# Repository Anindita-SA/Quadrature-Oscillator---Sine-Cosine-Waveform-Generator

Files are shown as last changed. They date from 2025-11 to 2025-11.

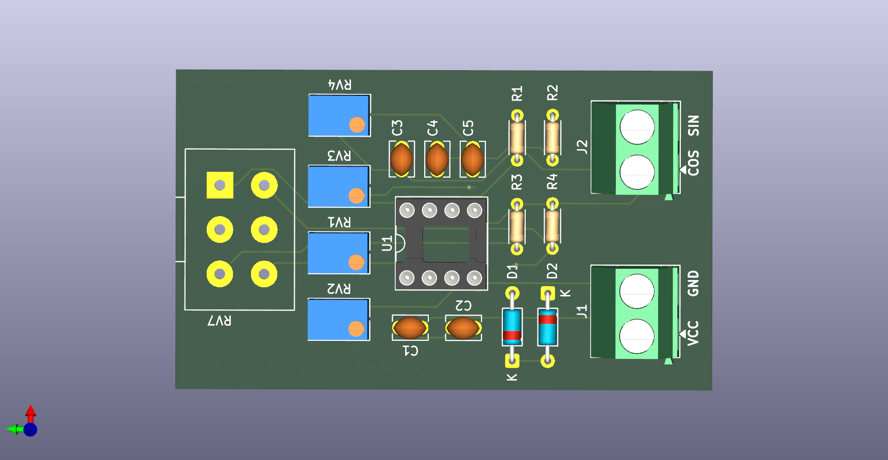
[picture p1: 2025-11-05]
PCB design for Quadrarure oscillator/Final PCB for 1khz Sine wave generator 123.png

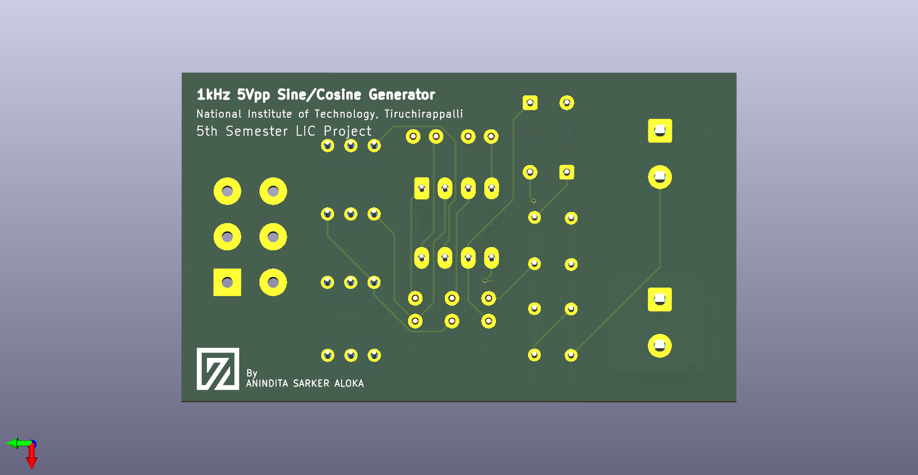
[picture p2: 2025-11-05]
PCB design for Quadrarure oscillator/Final PCB for 1khz Sine wave generator 12.png

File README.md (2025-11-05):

# Quadrature Oscillator - Sine/Cosine Waveform Generator

⚠️ **WORK IN PROGRESS** - Hardware optimization ongoing

## Overview

1kHz quadrature oscillator generating simultaneous sine and cosine waveforms with 90° phase relationship using op-amp integrators.

**Key Specs:**
- Frequency: 1 kHz
- Phase Difference: 90° (quadrature)
- Output: ~2.4V peak
- Supply: ±15V
- IC: LM358 dual op-amp

## Circuit Design



### Topology

State-variable quadrature oscillator implementing:

```
d(sine)/dt = ω × cosine
d(cosine)/dt = -ω × sine
```

### Schematic

[Final PCB for 1khz Sine wave generator 2.pdf](https://github.com/user-attachments/files/23353181/Final.PCB.for.1khz.Sine.wave.generator.2.pdf)

### Components

| Component | Value | Function |
|---|---|---|
| R1, R2, R3, R4 | 1.6kΩ | Frequency setting |
| C1, C2, C3 | 100nF | Integrator capacitors |
| R5, R7 | 1kΩ | Bias network |
| R6, R10 | 8kΩ | Voltage divider |
| D1, D2 | 1N4148 | Amplitude limiting |
| U1, U2 | LM358 | Op-amps (2 ICs) |

## Calculations

**Frequency:**
```
f = 1/(2πRC) = 1/(2π × 1.6kΩ × 100nF) ≈ 995 Hz
Measured: 1.01 kHz (±1%)
```

**Output Amplitude:**
```
V_bias = 15V × 1kΩ/9kΩ = 1.67V
V_peak = V_bias + V_diode = 1.67V + 0.7V = 2.37V
Measured: ~2.4V ✓
```

**Phase:**
```
Target: 90°
Measured: 83-85° (within tolerance)
```

## Performance





| Parameter | Target | Simulation | Hardware |
|---|---|---|---|
| Frequency | 1000 Hz | 1009 Hz | 1030 Hz |
| Phase | 90° | 91.7° | 83-85° |
| Amplitude | ~5V pp | 4.68V pp | ~2.4V |

## Design Evolution

1. **Wien Bridge** → Abandoned (complex amplitude control)
2. **All-Pass Filter** → Abandoned (wrong phase shift)
3. **Quadrature Oscillator** → Current (functional, optimizing)

## Known Issues

- **Hardware distortion** - LM358 slew rate limiting + breadboard parasitics
- **Phase accuracy** - Component tolerances cause 5-7° deviation
- **Amplitude variation** - Working on stabilization

## To-Do

- [ ] PCB implementation
- [ ] Add frequency adjustment potentiometer

## Files

- [[schematic.png](https://github.com/Anindita-SA/Quadrature-Oscillator-Sine-Cosine-Waveform-Generator/blob/61d378de57019a960dd601e74cefbcc4ff721f99/Final%20PCB%20for%201khz%20Sine%20w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)] - Circuit diagram
- [[simulation.asc](https://github.com/Anindita-SA/Quadrature-Oscillator-Sine-Cosine-Waveform-Generator/tree/61d378de57019a960dd601e74cefbcc4ff721f99/LTSpice%20simulation%20for%201kHz%2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)] - LTspice file
- `calculations.md` - Design math
- `troubleshooting.md` - Issues log

## Build Notes

**Critical:**
- Use **film capacitors** for C1, C2, C3 (not ceramic)
- Verify component markings ("103" = 10nF, "104" = 100nF)
- Add 0.1µF decoupling caps close to IC pins
- Keep wires short on breadboard

## References

- Horowitz & Hill, "Art of Electronics" (3rd Ed., §5.17)
- [YouTube reference video](https://www.youtube.com/watch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)

## License

Educational/open source - standard quadrature oscillator topology

## Contact

[[Github](https://github.com/Anindita-SA)]

**Status:** Active development - contributions welcome

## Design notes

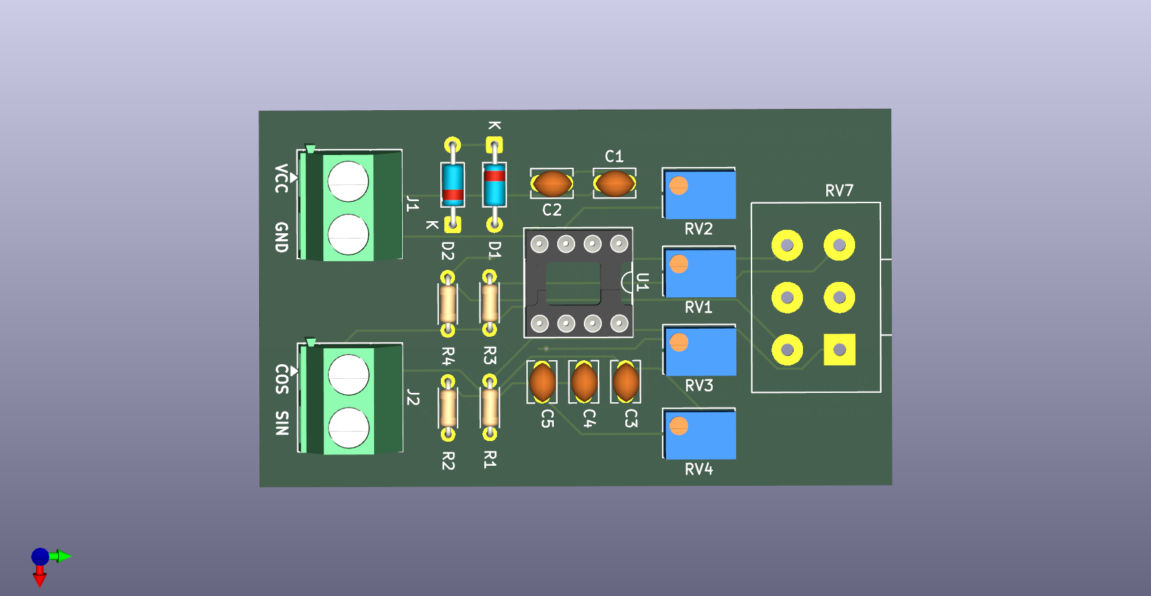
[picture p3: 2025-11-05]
Final PCB for 1khz Sine wave generator 1.png

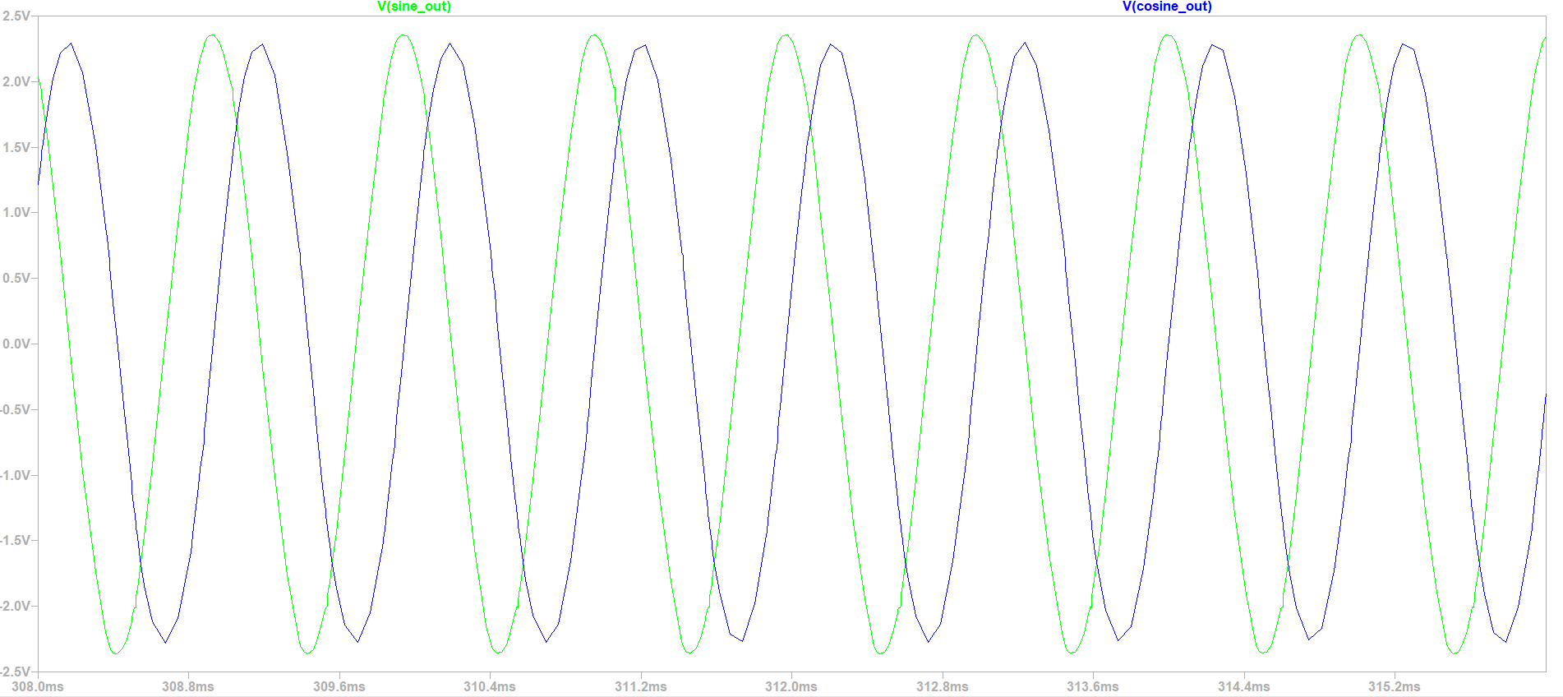
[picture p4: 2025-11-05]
LTSpice simulation for 1kHz SineCosine Generator/Screenshot 2025-11-05 121047.png

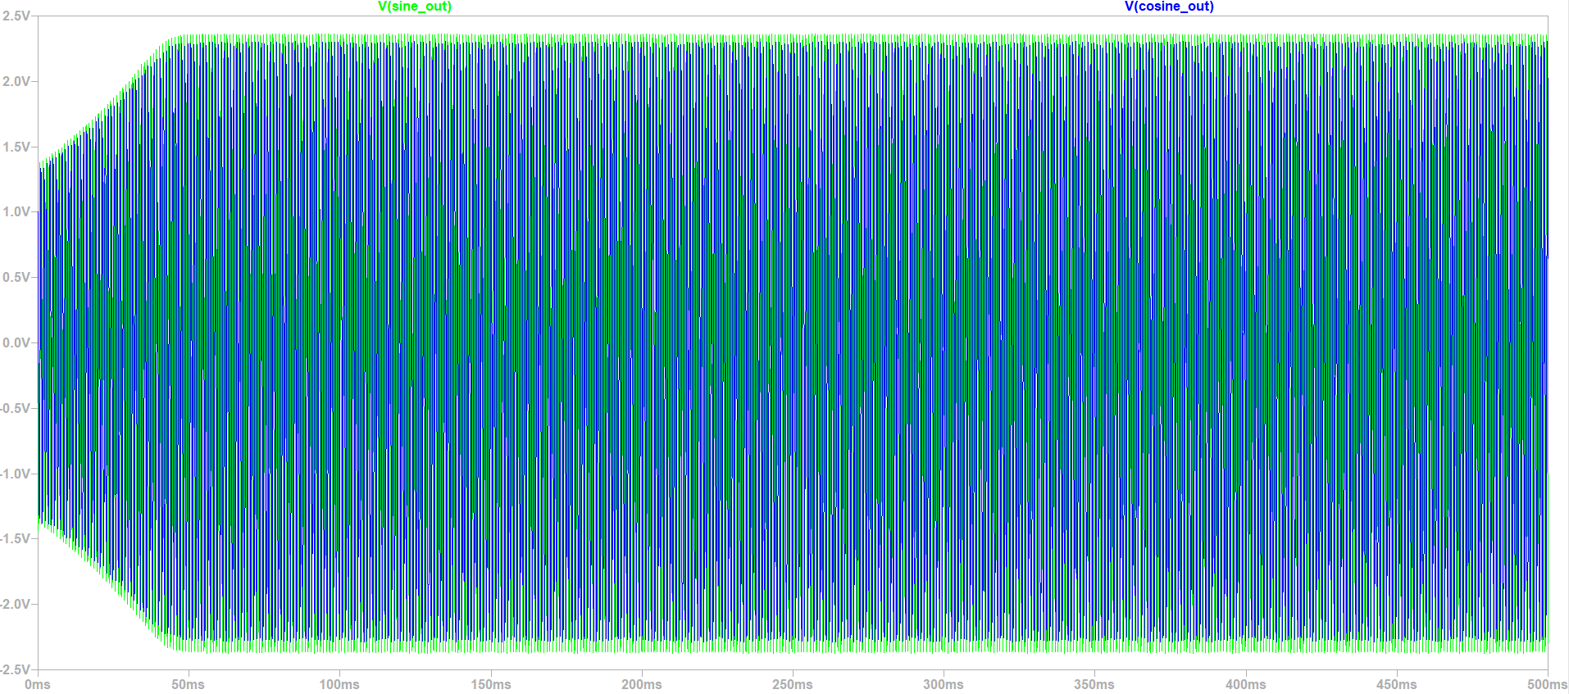
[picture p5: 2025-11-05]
LTSpice simulation for 1kHz SineCosine Generator/Screenshot 2025-11-05 121033.png

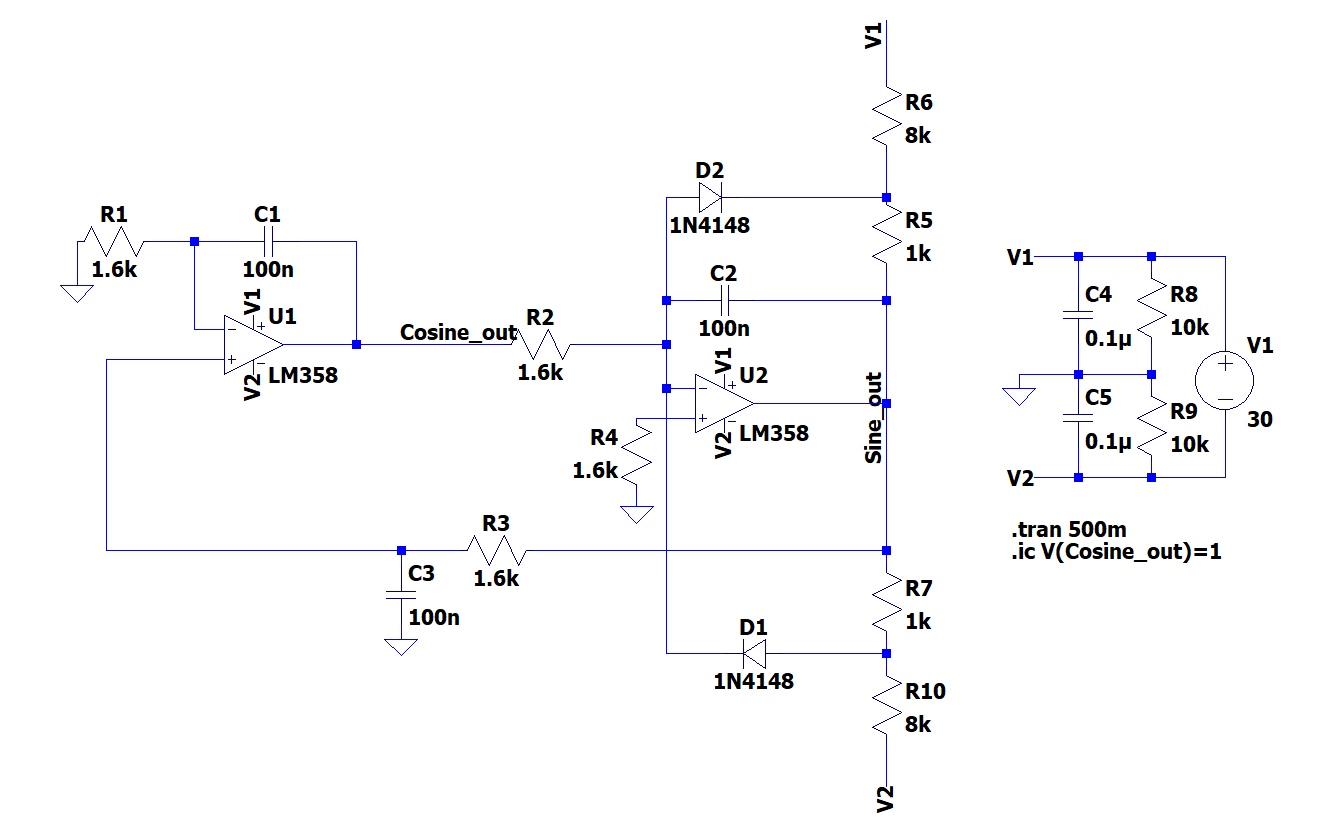
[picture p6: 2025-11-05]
LTSpice simulation for 1kHz SineCosine Generator/Screenshot 2025-11-05 121116.png

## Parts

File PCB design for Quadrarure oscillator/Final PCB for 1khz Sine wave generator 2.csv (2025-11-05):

Reference | Qty | Value | DNP | Exclude from BOM | Exclude from Board | Footprint | Datasheet
C1,C2,C3,C4,C5 | 5 | 100nF |  |  |  | Capacitor_THT:C_Disc_D3.8mm_W2.6mm_P2.50mm
J1 | 1 | Screw_Terminal_01x02 |  |  |  | TerminalBlock_Phoenix:TerminalBlock_Phoenix_MKDS-1,5-2-5.08_1x02_P5.08mm_Horizontal | ~
R1,R2 | 2 | 10k |  |  |  | Resistor_THT:R_Axial_DIN0204_L3.6mm_D1.6mm_P5.08mm_Horizontal | ~
RV1,RV2,RV3,RV4 | 4 | R_Potentiometer |  |  |  | Potentiometer_THT:Potentiometer_Bourns_3266Y_Vertical | ~
U1 | 1 | LM358 |  |  |  | Package_DIP:DIP-8_W7.62mm_Socket_LongPads | http://www.ti.com/lit/ds/symlink/lm2904-n.pdf

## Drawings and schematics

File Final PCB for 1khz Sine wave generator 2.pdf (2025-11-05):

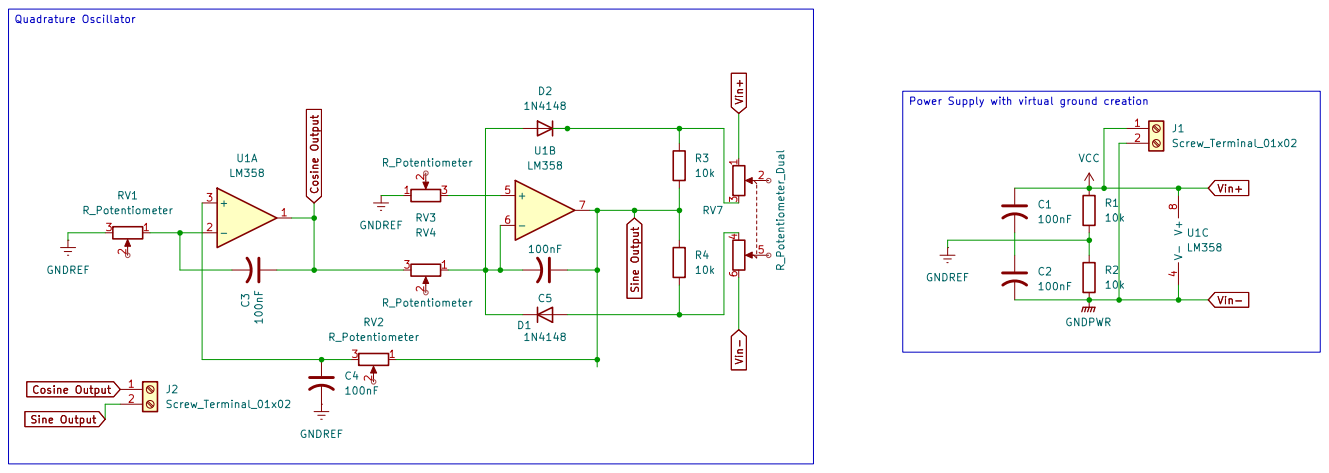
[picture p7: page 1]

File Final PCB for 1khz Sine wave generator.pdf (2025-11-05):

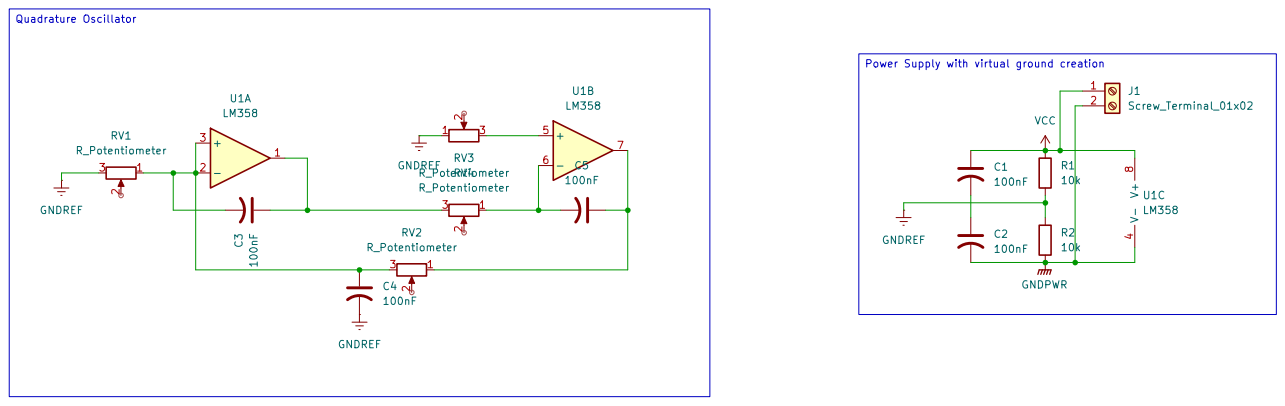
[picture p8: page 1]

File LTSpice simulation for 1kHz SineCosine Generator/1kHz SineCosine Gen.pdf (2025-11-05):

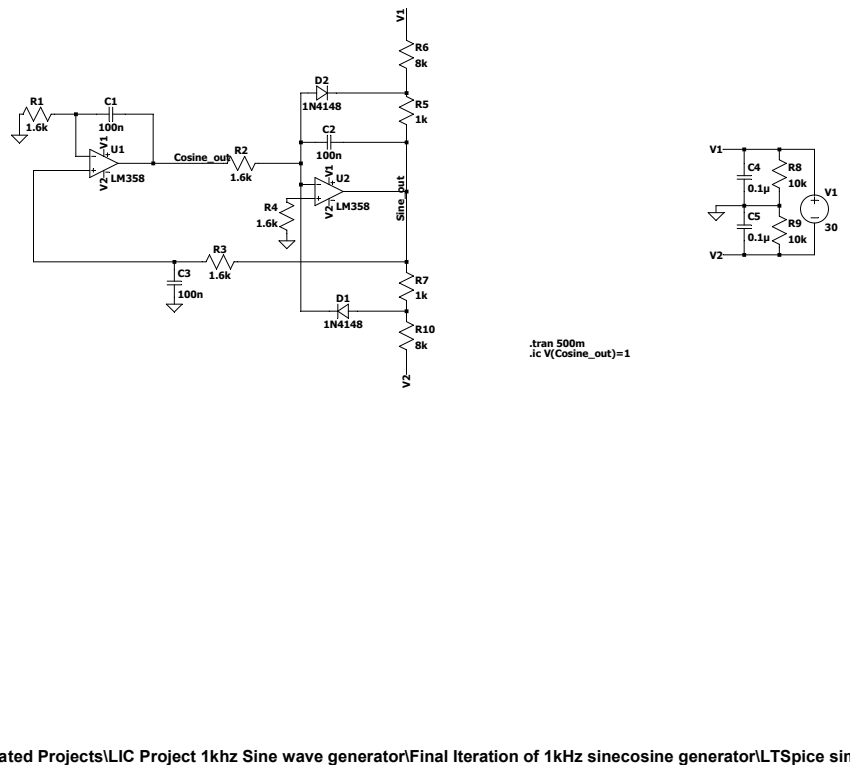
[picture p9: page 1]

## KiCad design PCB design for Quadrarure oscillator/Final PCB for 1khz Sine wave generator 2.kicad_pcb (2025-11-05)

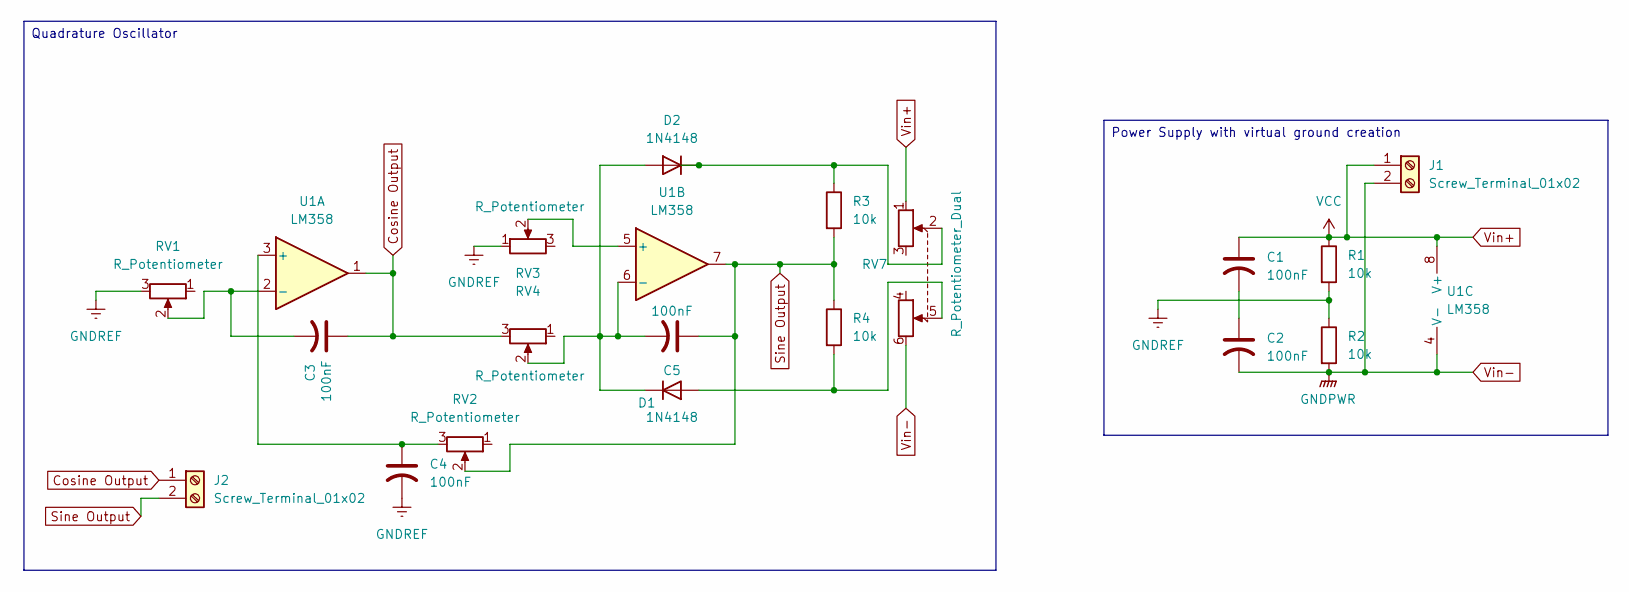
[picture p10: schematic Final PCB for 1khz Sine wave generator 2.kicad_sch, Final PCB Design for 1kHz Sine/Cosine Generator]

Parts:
C1, C2, C3, C4, C5: 100nF; C_Disc_D3.8mm_W2.6mm_P2.50mm
D1, D2: 1N4148; D_DO-35_SOD27_P7.62mm_Horizontal
J1, J2: Screw_Terminal_01x02; TerminalBlock_Phoenix_MKDS-1,5-2-5.08_1x02_P5.08mm_Horizont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
R1, R2, R3, R4: 10k; R_Axial_DIN0204_L3.6mm_D1.6mm_P5.08mm_Horizontal
RV1, RV2, RV3, RV4: R_Potentiometer; Potentiometer_Bourns_3266Y_Vertical
RV7: R_Potentiometer_Dual; Potentiometer_Alps_RK163_Dual_Horizontal
U1: LM358; DIP-8_W7.62mm_Socket_LongPads

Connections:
Cosine Output: C3.1, J2.1, RV4.3, U1.1
GNDREF: C4.2, R1.2, R2.1, RV1.3, RV3.1
unnamed: C1.2, C2.1
unnamed: D1.2 (A), R4.2, RV7.5
unnamed: C5.2, D1.1 (K), D2.2 (A), RV4.2, U1.6 (-)
unnamed: D2.1 (K), R3.1, RV7.2
unnamed: C4.1, RV2.3, U1.3 (+)
unnamed: C3.2, RV1.2, U1.2 (-)
unnamed: RV3.2, U1.5 (+)
Sine Output: C5.1, J2.2, R3.2, R4.1, RV2.2, U1.7
Vin+: C1.1, J1.1, R1.1, RV7.1, U1.8 (V+)
Vin-: C2.2, J1.2, R2.2, RV7.6, U1.4 (V-)

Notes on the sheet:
Power Supply with virtual ground creation
Quadrature Oscillator

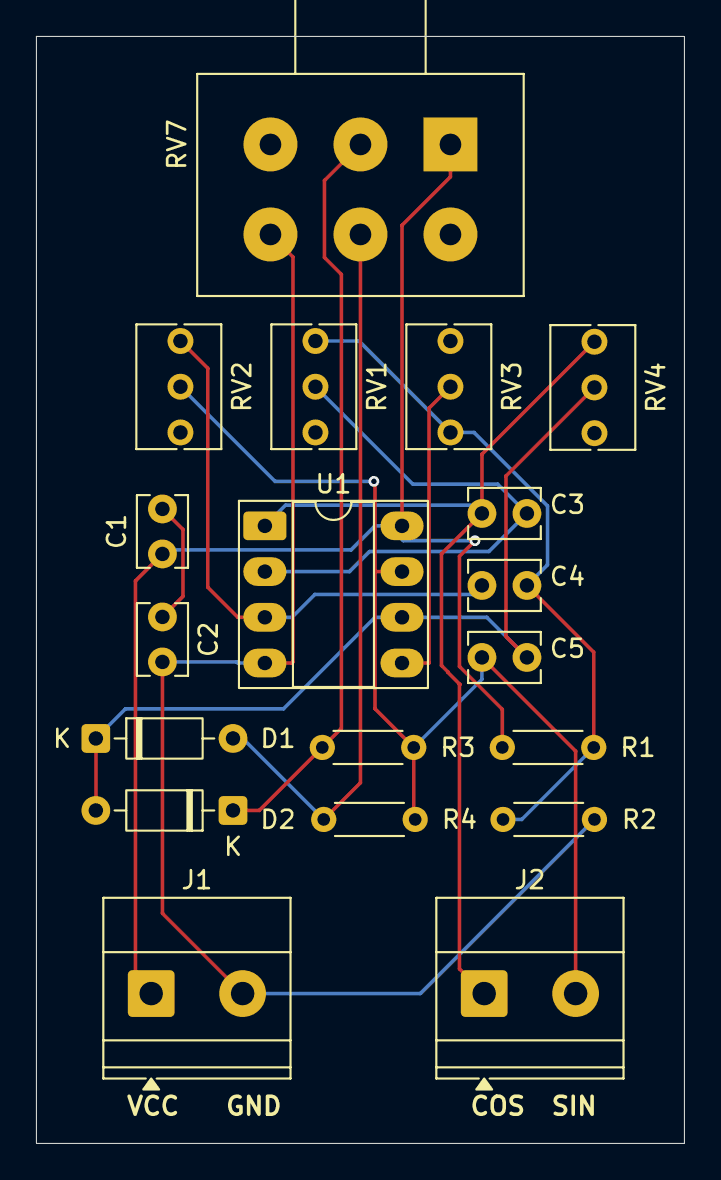
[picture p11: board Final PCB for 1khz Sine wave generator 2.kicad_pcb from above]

Board: 2 copper layers, 36.0 x 61.5 mm, 19 parts (0 on the bottom side), 12 nets.
